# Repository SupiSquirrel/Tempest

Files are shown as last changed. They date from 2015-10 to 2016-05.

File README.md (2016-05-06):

# Tempest
Tempest: Etek 5 / GTek / Drone 2 / Clone 5 / Shocker SFT/NXT Paintball Board

This product is open source!

## Hardware
The hardware is released under [Creative Commons ShareAlike 4.0 International](https://creativecommons.org/licenses/by-sa/4.0/).

Please use, reuse, and modify these files as you see fit. Please release anything derivative under the same license.

Distributed as-is; no warranty is given.

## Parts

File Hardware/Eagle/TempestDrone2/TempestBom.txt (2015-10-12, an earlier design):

Partlist

Exported from TempestDrone2.brd at 09.10.2015 22:12:44

EAGLE Version 6.6.0 Copyright (c) 1988-2014 CadSoft

Assembly variant: 

Part     Value                Package            Library  Position (mm)         Orientation

C1       dnp                  _0603MP            squirrel (22.6678 71.338)      R180
C2       dnp                  _0603MP            squirrel (22.727 76.1532)      R180
C3       2.2µ                 C0805              squirrel (31 58.9)             R0                  0.07
C4       100n                 _0603MP            squirrel (26.594 76.0612)      R180
C5       100n                 _0603MP            squirrel (26.389 67.6968)      R0
C6       100n                 _0603MP            squirrel (29.161 76.4612)      R0
C7       2.2µ                 C0805              squirrel (27.8 62)             R270                0.07
C9       100n                 _0603MP            squirrel (15.515471875 39.60048125) R90
C10      2.2µ                 _0603MP            squirrel (15.515475 36.90048125) R90               0.07
C24      22µ                  C1206              squirrel (30.7608 81.1564)     R90                 0.08
CON1     MOLEX_51281          MOLEX_51281        squirrel (24.49863125 82.601815625) R164           0,54
CON2     B2B-ZR               S2B-ZR             squirrel (30.7 57.3)           R0                  0.08
CON3     FE05-2HD-2           FE02-2-HD-2        squirrel (38.1 69.8)           R75                 0,39
CON5     FE05-2HD-2           FE02-2-HD-2        squirrel (22.915475 50.20048125) R180              0,39
CON7     FE05-2HD-2           FE02-2-HD-2        squirrel (37.707 79.5122)      R345                0,57
D1       SOD123               SOD123             squirrel (27.497 56.9398)      R270                0,15
D3       BAT54C               SOT23              diode    (35.776 60.8942)      R270                0.04
IC1      ATSAMD21E            QFN-32             squirrel (28.234 72.0622)      R270                2.59
LED1     LED-TRICOLORSMD_SIDE RGB-LED-SMD-SIDE   squirrel (45.146184375 31.732578125) R185          0.56
Q1       dnp                  XTAL_32X15         squirrel (23.362 74.5022)      R90
R1       10K                  _0603MP            squirrel (32.3388 76.001)      R90
R2       100K                 _0603MP            squirrel (37.2 58.7)           R90
R3       100K                 _0603MP            squirrel (52.8 62.8)           R0
R4       10K                  _0603MP            squirrel (35.124 57.9728)      R0
R5       18K                  _0603MP            squirrel (25.7612 57.154)      R90
R7       100K                 _0603MP            squirrel (28.015475 49.20048125) R90
R10      390                  _0603MP            squirrel (19.2392 72.1696)     R270
R14      1K                   _0603MP            squirrel (44.7 35.2)           R90
R15      1K                   _0603MP            squirrel (42.5 35.2)           R90
R16      1K                   _0603MP            squirrel (43.6 35.2)           R90
S1       SWITCH-BUTTONSIDE_EZ TACTILE-PTH-SIDEEZ squirrel (44.991284375 20.99961875) R95            0,27
S2       SWITCH-BUTTONSIDE_EZ TACTILE-PTH-SIDEEZ squirrel (46.036003125 10.575375) R95              0,27
S3       SWITCH-BUTTON        D2F-A              squirrel (24.6304 60.17135)    R345                1.36
SW3      PUSHBUTTONMICRO2     PUSHBUTTON-MICRO2  squirrel (36.7122 55.697)      R180                0.72 
U$1      AMS002               AMS00X             AMS00x   (17.215475 46.60048125) R270              8,49
U1       TPS709               SOT23-5            squirrel (31.3 62)             R0                  0.78
---------------------------------------------------------------------------------------------------------
                                                                                                   17.14
                                                                                                   24.32 Fab

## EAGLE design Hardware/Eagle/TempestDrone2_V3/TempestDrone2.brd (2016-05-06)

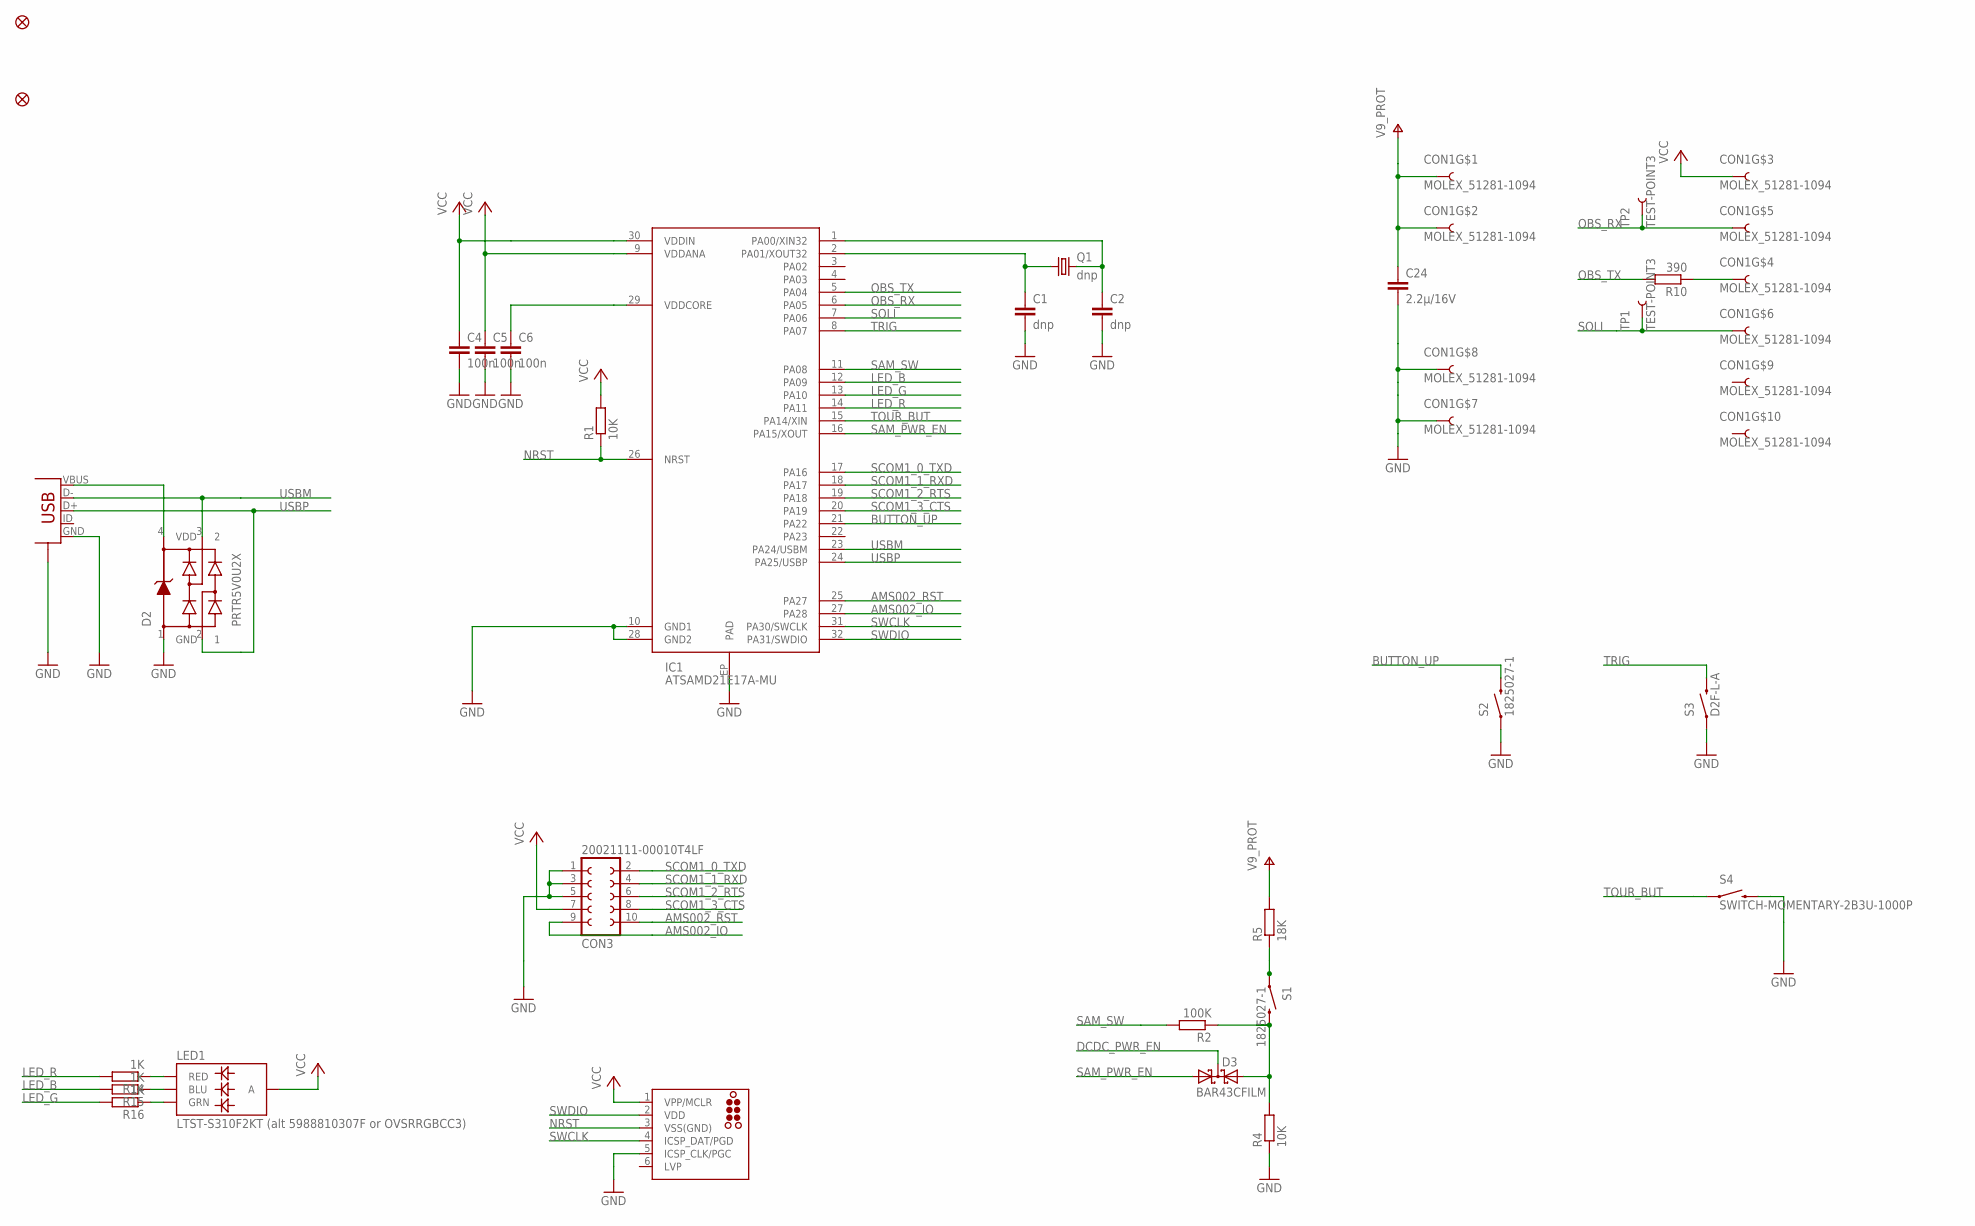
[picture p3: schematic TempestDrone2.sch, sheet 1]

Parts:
C1, C2: dnp; _0603MP
C4, C5, C6: 100n; _0603MP
C24: 2.2µ/16V; C0805
CON1: MOLEX_51281-1094; MOLEX_51281; PART# 51281-1094
CON3: 20021111-00010T4LF; FE02-2-HD-2; PART# 20021111-00010T4LF
CON4: USB-MICRO-A; USB-MICROB; PART# ZX62-B-5PA(11)
D2: PRTR5V0U2X; AUTOPILOT_SOT143B; PART# PRTR5V0U2X
D3: BAR43CFILM; SOT23
FID1, FID6: FIDUCIALUFIDUCIAL; MICRO-FIDUCIAL
IC1: ATSAMD21E17A-MU; QFN-32; PART# ATSAMD21E17A-MU
LED1: LTST-S310F2KT (alt 5988810307F or OVSRRGBCC3); RGB-LED-SMD-SIDE; PART# LTST-S310F2KT
Q1: dnp; XTAL_32X15
R1, R4: 10K; _0603MP
R2: 100K; _0603MP
R5: 18K; _0603MP
R10: 390; _0603MP
R14, R15, R16: 1K; _0603MP
S1, S2: 1825027-1; TACTILE-PTH-SIDEEZ; PART# 1-1825027-1
S3: D2F-L-A; D2F-A; PART# D2F-L-A
S4: SWITCH-MOMENTARY-2B3U-1000P; PUSHBUTTON-MICRO3; PART# B3U-1000P
TC2030-CTX-NL: dnp; TC2030-MCP-NL
TP1, TP2: TEST-POINT3; PAD.03X.03

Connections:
AMS002_IO: CON3.9, IC1.27 (PA28)
AMS002_RST: CON3.10, IC1.25 (PA27)
BUTTON_UP: IC1.21 (PA22), S2.2
DCDC_PWR_EN: D3.3 (CC); also elsewhere on the board
GND: C1.2, C2.2, C4.2, C5.2, C6.2, C24.2, CON1.7, CON1.8, CON3.1, CON3.3, CON3.5, CON4.GND, CON4.GND@1 (GND), CON4.GND@2 (GND), CON4.GND@3 (GND), CON4.GND@4 (GND), CON4.GND@5 (GND), CON4.GND@6 (GND), D2.1 (GND), IC1.10 (GND1), IC1.28 (GND2), IC1.EP (PAD), R4.1, S2.1, S3.COM (1), S4.2A (2), TC2030-CTX-NL.5 (ICSP_CLK/PGC); also elsewhere on the board
LED_B: IC1.12 (PA09), R15.2
LED_G: IC1.13 (PA10), R16.2
LED_R: IC1.14 (PA11), R14.2
unnamed: C2.1, IC1.1 (PA00/XIN32), Q1.2
unnamed: C6.1, IC1.29 (VDDCORE)
unnamed: C1.1, IC1.2 (PA01/XOUT32), Q1.1
unnamed: CON4.VBUS, D2.4 (VDD)
unnamed: D3.2 (A2), R2.1, R4.2, S1.2
unnamed: CON1.4, R10.1
unnamed: R5.1, S1.1
unnamed: LED1.1 (RED), R14.1
unnamed: LED1.3 (BLU), R15.1
unnamed: LED1.2 (GRN), R16.1
NRST: IC1.26 (NRST), R1.1, TC2030-CTX-NL.3 (VSS(GND))
OBS_RX: CON1.5, IC1.6 (PA05), TP2.P$1
OBS_TX: IC1.5 (PA04), R10.2
SAM_PWR_EN: D3.1 (A1), IC1.16 (PA15/XOUT)
SAM_SW: IC1.11 (PA08), R2.2
SCOM1_0_TXD: CON3.2, IC1.17 (PA16)
SCOM1_1_RXD: CON3.4, IC1.18 (PA17)
SCOM1_2_RTS: CON3.6, IC1.19 (PA18)
SCOM1_3_CTS: CON3.8, IC1.20 (PA19)
SOLI: CON1.6, IC1.7 (PA06), TP1.P$1
SWCLK: IC1.31 (PA30/SWCLK), TC2030-CTX-NL.4 (ICSP_DAT/PGD)
SWDIO: IC1.32 (PA31/SWDIO), TC2030-CTX-NL.2 (VDD)
TOUR_BUT: IC1.15 (PA14/XIN), S4.1A (1)
TRIG: IC1.8 (PA07), S3.NO (2)
USBM: CON4.D-, D2.3 (2), IC1.23 (PA24/USBM)
USBP: CON4.D+, D2.2 (1), IC1.24 (PA25/USBP)
V9_PROT: C24.1, CON1.1, CON1.2, R5.2; also elsewhere on the board
VCC: C4.1, C5.1, CON1.3, CON3.7, IC1.9 (VDDANA), IC1.30 (VDDIN), LED1.4 (A), R1.2, TC2030-CTX-NL.1 (VPP/MCLR); also elsewhere on the board

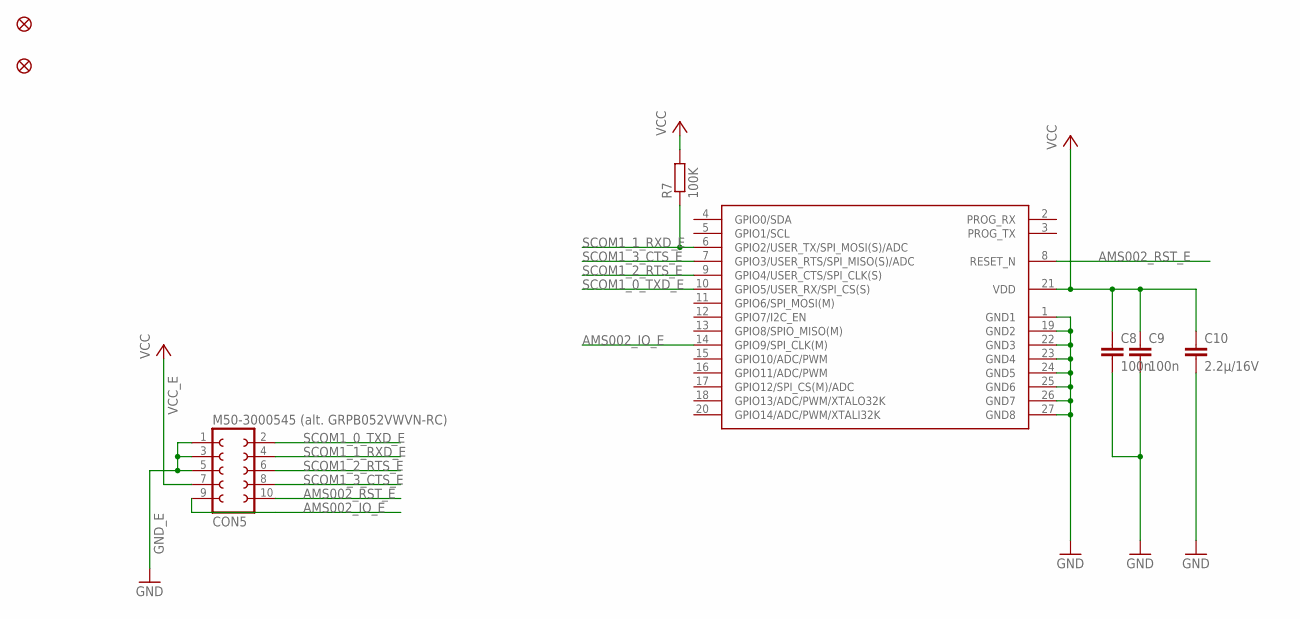
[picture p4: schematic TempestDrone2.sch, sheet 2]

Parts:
C8, C9: 100n; _0603MP
C10: 2.2µ/16V; C0805
CON5: M50-3000545 (alt. GRPB052VWVN-RC); FE02-2-HD-2; PART# M50-3000545
FID3, FID5: FIDUCIALUFIDUCIAL; MICRO-FIDUCIAL
R7: 100K; _0603MP
U$1: AMS001/AMS002; AMS00X; PART# AMS001 or AMS002

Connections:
AMS002_IO_E: CON5.9, U$1.14 (GPIO9/SPI_CLK(M))
AMS002_RST_E: CON5.10, U$1.8 (RESET_N)
GND_E: C8.2, C9.2, C10.2, CON5.1, CON5.3, CON5.5, U$1.1 (GND1), U$1.19 (GND2), U$1.22 (GND3), U$1.23 (GND4), U$1.24 (GND5), U$1.25 (GND6), U$1.26 (GND7), U$1.27 (GND8)
SCOM1_0_TXD_E: CON5.2, U$1.10 (GPIO5/USER_RX/SPI_CS(S))
SCOM1_1_RXD_E: CON5.4, R7.1, U$1.6 (GPIO2/USER_TX/SPI_MOSI(S)/ADC)
SCOM1_2_RTS_E: CON5.6, U$1.9 (GPIO4/USER_CTS/SPI_CLK(S))
SCOM1_3_CTS_E: CON5.8, U$1.7 (GPIO3/USER_RTS/SPI_MISO(S)/ADC)
VCC_E: C8.1, C9.1, C10.1, CON5.7, R7.2, U$1.21 (VDD)

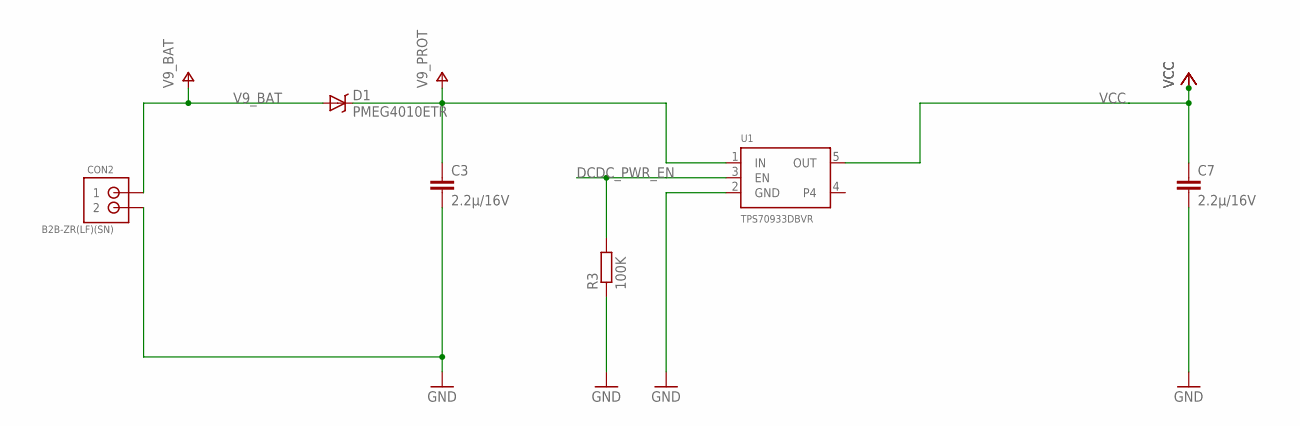
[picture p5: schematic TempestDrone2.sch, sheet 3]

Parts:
C3, C7: 2.2µ/16V; C0805
CON2: B2B-ZR(LF)(SN); S2B-ZR; PART# B2B-ZR(LF)(SN)
D1: PMEG4010ETR; SOD123
R3: 100K; _0603MP
U1: TPS70933DBVR; SOT23-5; PART# TPS70933DBVR

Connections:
DCDC_PWR_EN: R3.2, U1.3 (EN); also elsewhere on the board
GND: C3.2, C7.2, CON2.2, R3.1, U1.2 (GND); also elsewhere on the board
V9_BAT: CON2.1, D1.A
V9_PROT: C3.1, D1.C, U1.1 (IN); also elsewhere on the board
VCC: C7.1, U1.5 (OUT); also elsewhere on the board

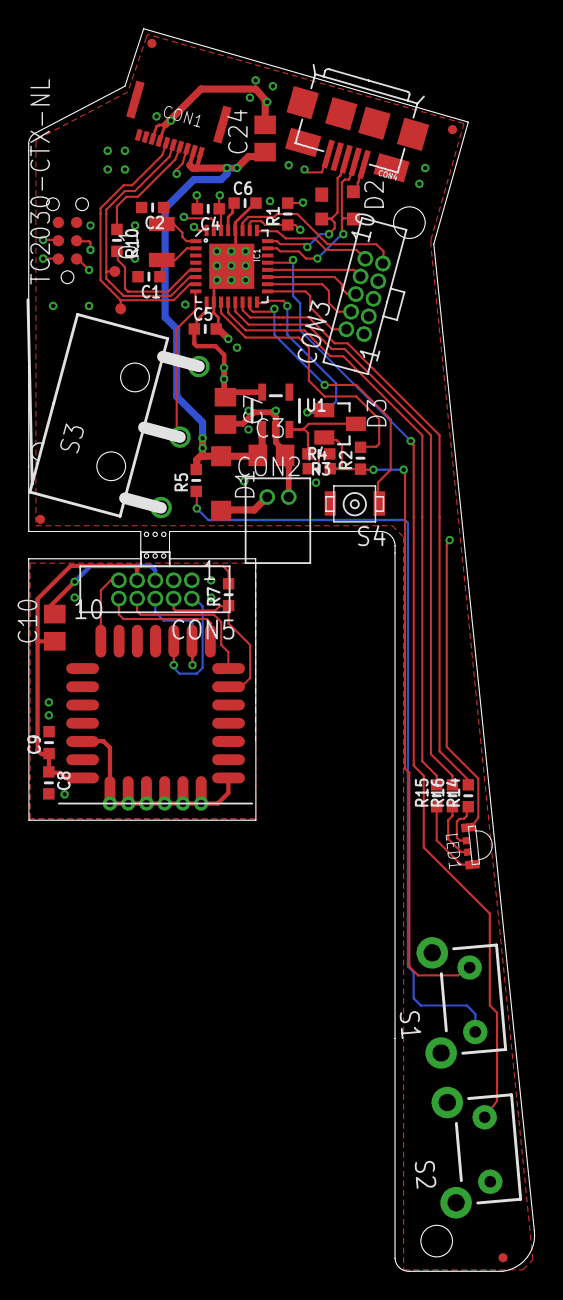
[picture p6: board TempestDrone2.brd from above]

Board: 4 copper layers, 35.2 x 86.5 mm, 45 parts (0 on the bottom side), 45 nets.

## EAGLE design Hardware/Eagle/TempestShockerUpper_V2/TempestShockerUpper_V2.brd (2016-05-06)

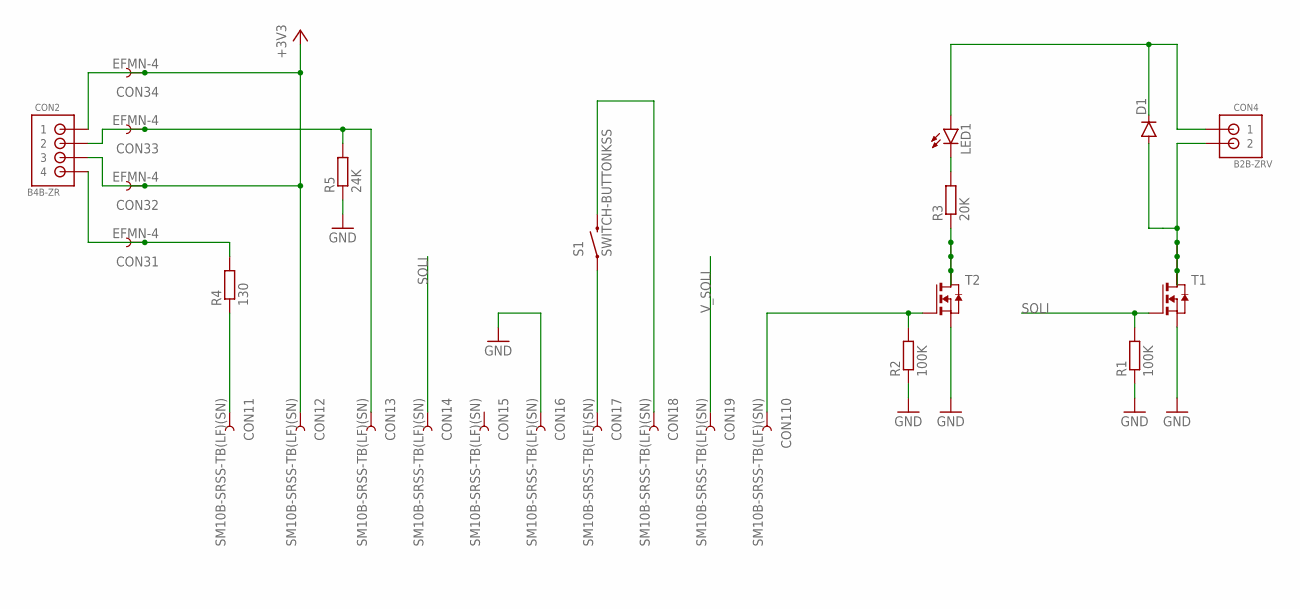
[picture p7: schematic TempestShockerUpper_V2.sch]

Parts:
CON1: SM10B-SRSS-TB(LF)(SN); SM10B-SRSS-TB
CON2: B4B-ZR; S4B-ZR
CON3: EFMN-4
CON4: B2B-ZRV; S2B-ZR-VERT
D1: DIODE-SSOD123; SOD-123
LED1: LED0603; LED-0603
R1, R2: 100K; _0603MP
R3: 20K; _0603MP
R4: 130; _0603MP
R5: 24K; _0603MP
S1: SWITCH-BUTTONKSS; KSS
T1, T2: NMOSSOT23-6; SOT23-6

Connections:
+3V3: CON1.2, CON2.1, CON2.3, CON3.2, CON3.4
GND: CON1.6, R1.1, R2.1, R5.1, T1.4 (S), T2.4 (S)
unnamed: CON2.4, CON3.1, R4.2
unnamed: CON1.1, R4.1
unnamed: CON1.3, CON2.2, CON3.3, R5.2
unnamed: CON1.10, R2.2, T2.3 (G)
unnamed: CON1.7, S1.1
unnamed: CON1.8, S1.2
unnamed: LED1.C, R3.2
unnamed: R3.1, T2.1 (D), T2.2 (D1), T2.5 (D2), T2.6 (D3)
unnamed: CON4.2, D1.A, T1.1 (D), T1.2 (D1), T1.5 (D2), T1.6 (D3)
SOLI: CON1.4, R1.2, T1.3 (G)
V_SOLI: CON1.9, CON4.1, D1.C, LED1.A

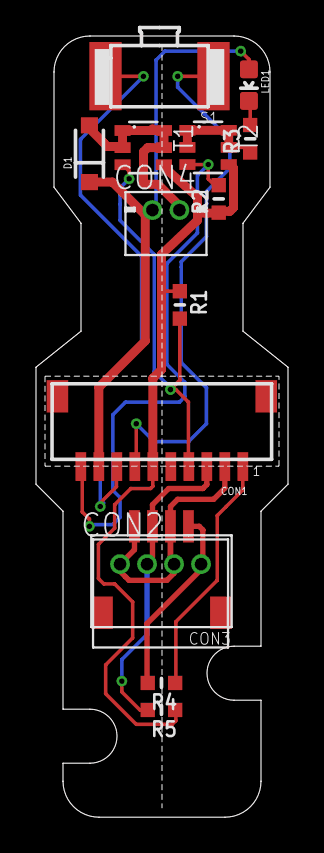
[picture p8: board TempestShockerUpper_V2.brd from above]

Board: 2 copper layers, 14.0 x 43.4 mm, 15 parts (0 on the bottom side), 13 nets.

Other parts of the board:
U$2: SHOCKER-OUTLINE-UPPER-SHORT

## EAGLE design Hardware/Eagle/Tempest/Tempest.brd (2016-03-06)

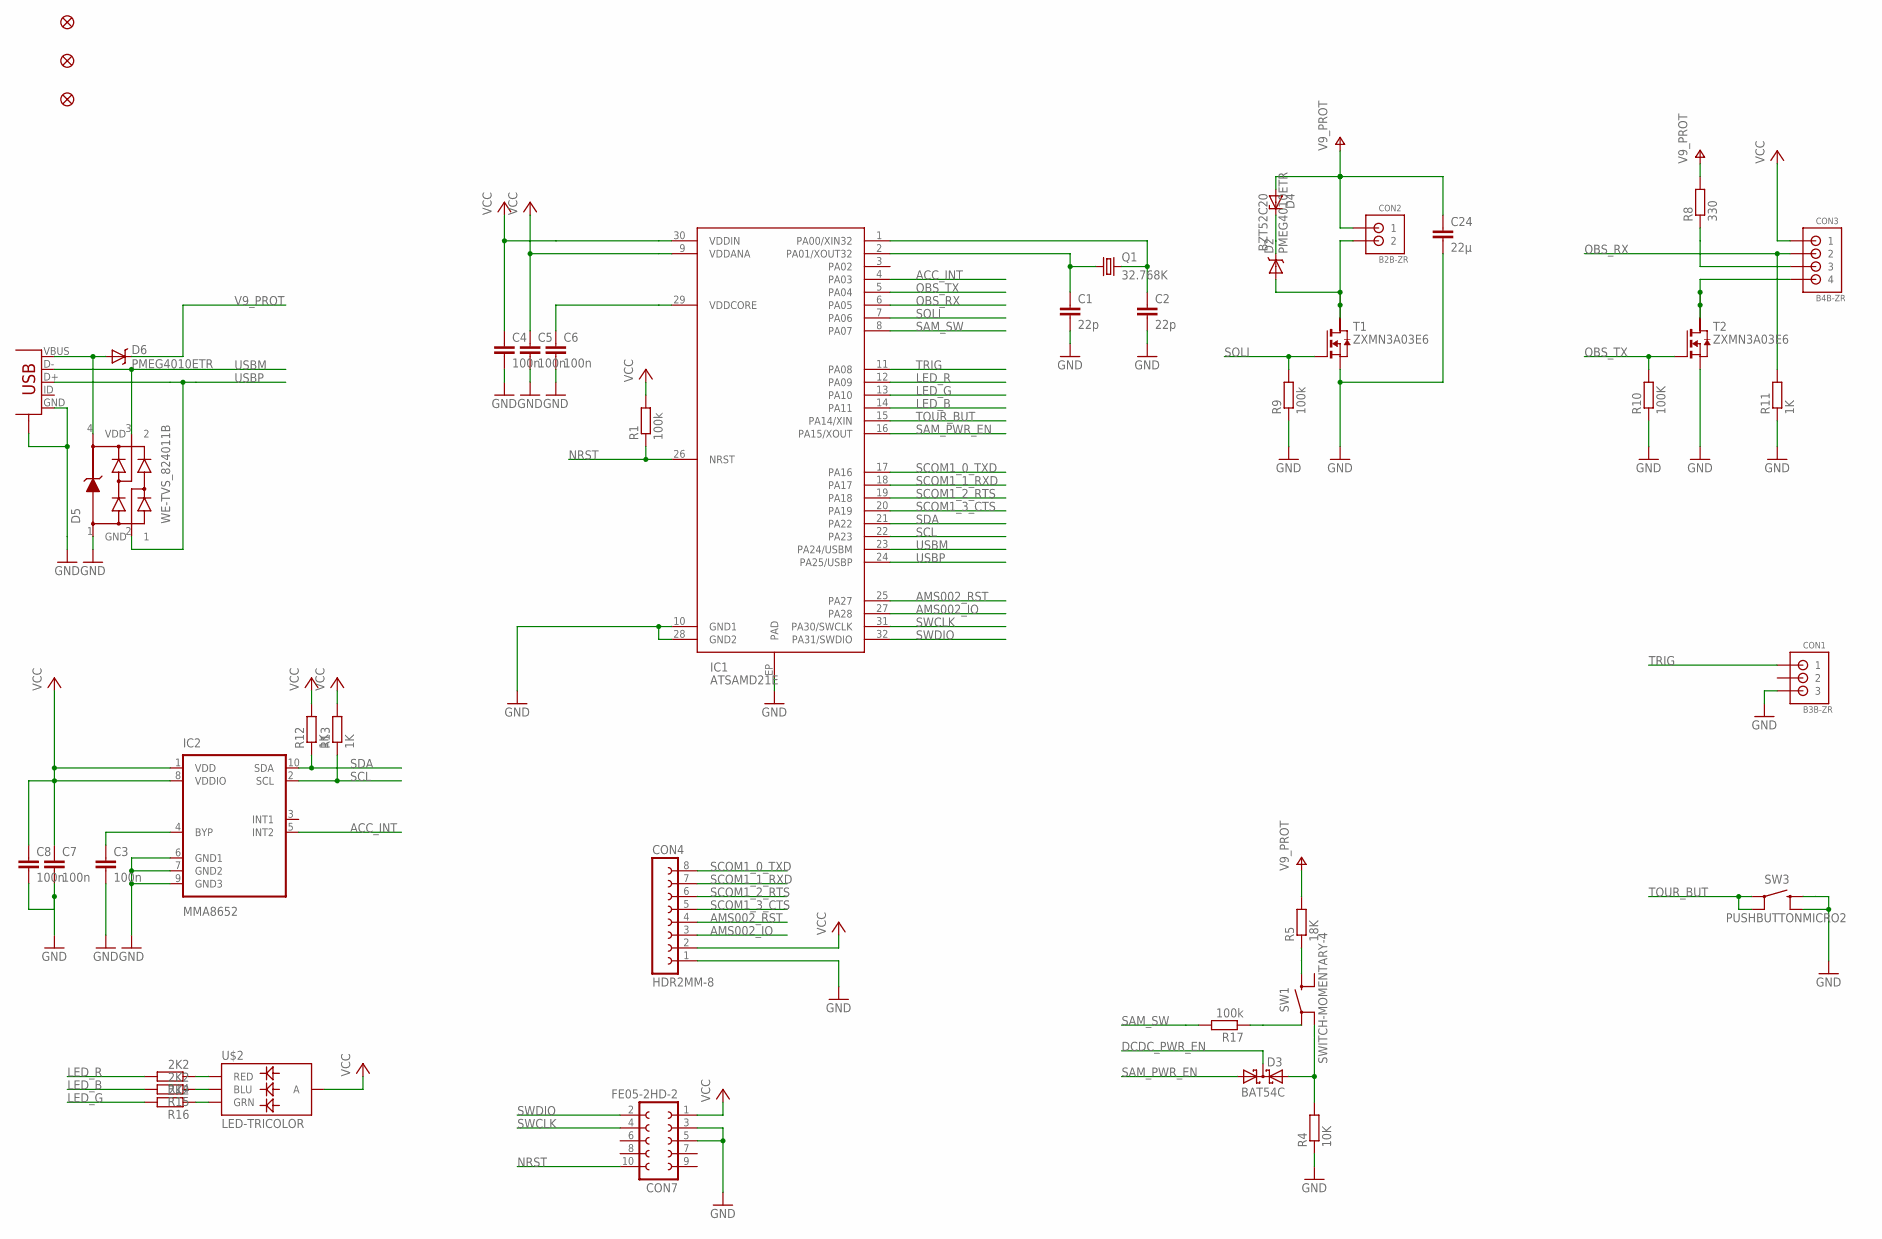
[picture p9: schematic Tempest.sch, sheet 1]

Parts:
C1, C2: 22p; _0603MP
C3, C4, C5, C6, C7, C8: 100n; _0603MP
C24: 22µ; C1206
CON1: B3B-ZR; S3B-ZR
CON2: B2B-ZR; S2B-ZR
CON3: B4B-ZR; S4B-ZR
CON4: HDR2MM-8
CON6: USB-MICRO-A; USB-MICROB
CON7: FE05-2HD-2; FE02-2-HD-2
D2, D6: PMEG4010ETR; SOD123
D3: BAT54C; SOT23
D4: BZT52C20; SOD123
D5: WE-TVS_824011B; AUTOPILOT_SOT143B
FID1, FID2, FID6: FIDUCIALUFIDUCIAL; MICRO-FIDUCIAL
IC1: ATSAMD21E; QFN-32
IC2: MMA8652; DFN-10
Q1: 32.768K; XTAL_32X15
R1, R9, R17: 100k; _0603MP
R4: 10K; _0603MP
R5: 18K; _0603MP
R8: 330; R0805
R10: 100K; _0603MP
R11, R12, R13: 1K; _0603MP
R14, R15, R16: 2K2; _0603MP
SW1: SWITCH-MOMENTARY-4; TACTILE_SWITCH_TALL
SW3: PUSHBUTTONMICRO2; PUSHBUTTON-MICRO2
T1, T2: ZXMN3A03E6; SOT23-6
U$2: LED-TRICOLOR; LED-TRICOLOR-SMD

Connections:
ACC_INT: IC1.4 (PA03), IC2.5 (INT2)
AMS002_IO: CON4.3, IC1.27 (PA28)
AMS002_RST: CON4.4, IC1.25 (PA27)
DCDC_PWR_EN: D3.3 (CC); also elsewhere on the board
GND: C1.2, C2.2, C3.2, C4.2, C5.2, C6.2, C7.2, C8.2, C24.2, CON1.3, CON4.1, CON6.GND, CON6.GND@1 (GND), CON6.GND@2 (GND), CON6.GND@3 (GND), CON6.GND@4 (GND), CON6.GND@5 (GND), CON6.GND@6 (GND), CON7.3, CON7.5, D5.1 (GND), IC1.10 (GND1), IC1.28 (GND2), IC1.EP (PAD), IC2.6 (GND1), IC2.7 (GND2), IC2.9 (GND3), R4.1, R9.1, R10.1, R11.1, SW3.2A (2), SW3.2B (2A), T1.4 (S), T2.4 (S); also elsewhere on the board
LED_B: IC1.14 (PA11), R15.2
LED_G: IC1.13 (PA10), R16.2
LED_R: IC1.12 (PA09), R14.2
unnamed: C2.1, IC1.1 (PA00/XIN32), Q1.2
unnamed: C6.1, IC1.29 (VDDCORE)
unnamed: C1.1, IC1.2 (PA01/XOUT32), Q1.1
unnamed: D3.2 (A2), R4.2, SW1.A2 (1A)
unnamed: CON2.2, D2.A, T1.1 (D), T1.2 (D1), T1.6 (D3)
unnamed: R5.1, SW1.B1 (2)
unnamed: R17.1, SW1.A1 (1)
unnamed: C3.1, IC2.4 (BYP)
unnamed: CON3.4, T2.1 (D), T2.2 (D1), T2.6 (D3)
unnamed: CON3.3, R8.1
unnamed: D2.C, D4.C
unnamed: CON6.VBUS, D5.4 (VDD), D6.A
unnamed: R14.1, U$2.2 (RED)
unnamed: R15.1, U$2.3 (BLU)
unnamed: R16.1, U$2.4 (GRN)
NRST: CON7.10, IC1.26 (NRST), R1.1
OBS_RX: CON3.2, IC1.6 (PA05), R11.2
OBS_TX: IC1.5 (PA04), R10.2, T2.3 (G)
SAM_PWR_EN: D3.1 (A1), IC1.16 (PA15/XOUT)
SAM_SW: IC1.8 (PA07), R17.2
SCL: IC1.22 (PA23), IC2.2 (SCL), R13.1
SCOM1_0_TXD: CON4.8, IC1.17 (PA16)
SCOM1_1_RXD: CON4.7, IC1.18 (PA17)
SCOM1_2_RTS: CON4.6, IC1.19 (PA18)
SCOM1_3_CTS: CON4.5, IC1.20 (PA19)
SDA: IC1.21 (PA22), IC2.10 (SDA), R12.1
SOLI: IC1.7 (PA06), R9.2, T1.3 (G)
SWCLK: CON7.4, IC1.31 (PA30/SWCLK)
SWDIO: CON7.2, IC1.32 (PA31/SWDIO)
TOUR_BUT: IC1.15 (PA14/XIN), SW3.1A (1), SW3.1B (1A)
TRIG: CON1.1, IC1.11 (PA08)
USBM: CON6.D-, D5.3 (2), IC1.23 (PA24/USBM)
USBP: CON6.D+, D5.2 (1), IC1.24 (PA25/USBP)
V9_PROT: C24.1, CON2.1, D4.A, D6.C, R5.2, R8.2; also elsewhere on the board
VCC: C4.1, C5.1, C7.1, C8.1, CON3.1, CON4.2, CON7.1, IC1.9 (VDDANA), IC1.30 (VDDIN), IC2.1 (VDD), IC2.8 (VDDIO), R1.2, R12.2, R13.2, U$2.1 (A); also elsewhere on the board

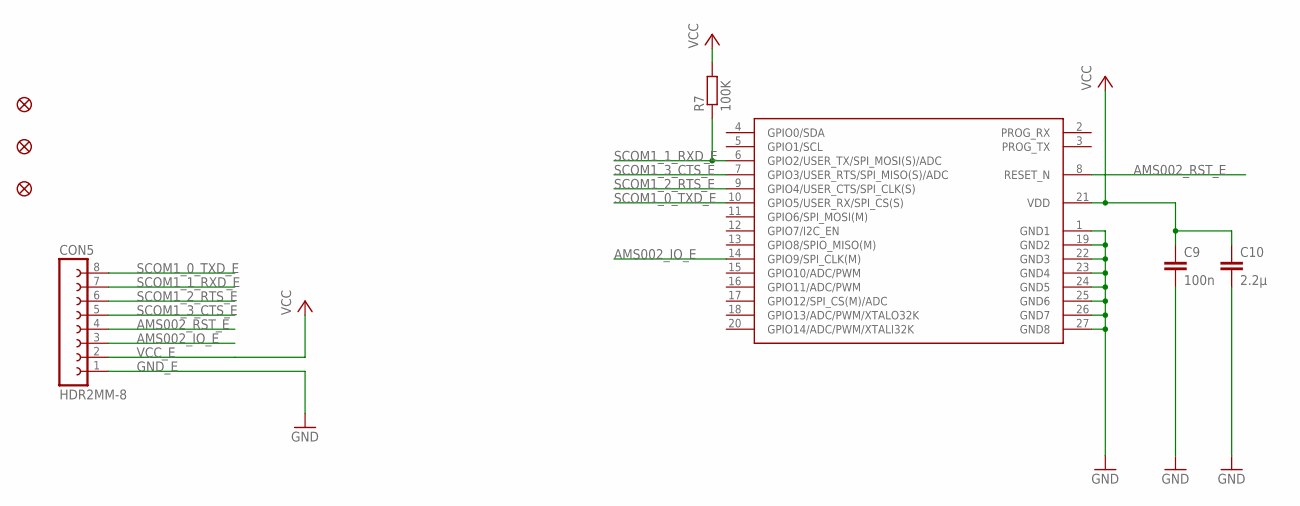
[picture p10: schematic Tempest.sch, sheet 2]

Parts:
C9: 100n; _0603MP
C10: 2.2µ; _0603MP
CON5: HDR2MM-8
FID3, FID4, FID5: FIDUCIALUFIDUCIAL; MICRO-FIDUCIAL
R7: 100K; _0603MP
U$1: AMS002; AMS00X

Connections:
AMS002_IO_E: CON5.3, U$1.14 (GPIO9/SPI_CLK(M))
AMS002_RST_E: CON5.4, U$1.8 (RESET_N)
GND_E: C9.2, C10.2, CON5.1, U$1.1 (GND1), U$1.19 (GND2), U$1.22 (GND3), U$1.23 (GND4), U$1.24 (GND5), U$1.25 (GND6), U$1.26 (GND7), U$1.27 (GND8)
SCOM1_0_TXD_E: CON5.8, U$1.10 (GPIO5/USER_RX/SPI_CS(S))
SCOM1_1_RXD_E: CON5.7, R7.1, U$1.6 (GPIO2/USER_TX/SPI_MOSI(S)/ADC)
SCOM1_2_RTS_E: CON5.6, U$1.9 (GPIO4/USER_CTS/SPI_CLK(S))
SCOM1_3_CTS_E: CON5.5, U$1.7 (GPIO3/USER_RTS/SPI_MISO(S)/ADC)
VCC_E: C9.1, C10.1, CON5.2, R7.2, U$1.21 (VDD)

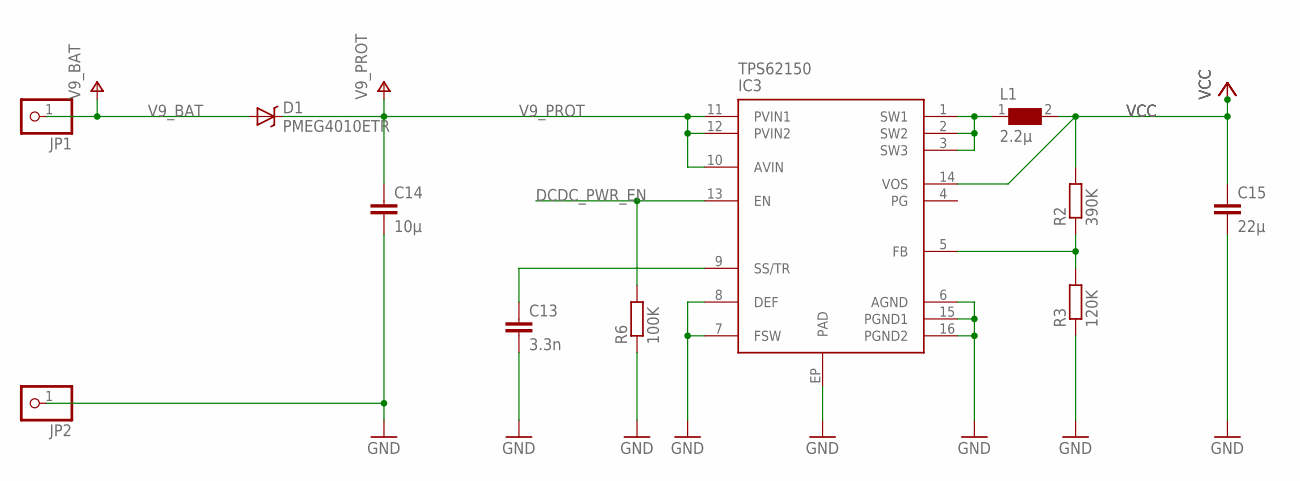
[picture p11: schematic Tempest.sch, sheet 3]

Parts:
C13: 3.3n; _0603MP
C14: 10µ; C1206
C15: 22µ; C1206
D1: PMEG4010ETR; SOD123
IC3: TPS62150; QFN-16
JP1, JP2: PINHD-1X1; 1X01
L1: 2.2µ; WE-TPC_2828
R2: 390K; _0603MP
R3: 120K; _0603MP
R6: 100K; _0603MP

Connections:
DCDC_PWR_EN: IC3.13 (EN), R6.2; also elsewhere on the board
GND: C13.2, C14.2, C15.2, IC3.6 (AGND), IC3.7 (FSW), IC3.8 (DEF), IC3.15 (PGND1), IC3.16 (PGND2), IC3.EP (PAD), JP2.1, R3.1, R6.1; also elsewhere on the board
unnamed: C13.1, IC3.9 (SS/TR)
unnamed: IC3.1 (SW1), IC3.2 (SW2), IC3.3 (SW3), L1.1
unnamed: IC3.5 (FB), R2.1, R3.2
V9_BAT: D1.A, JP1.1
V9_PROT: C14.1, D1.C, IC3.10 (AVIN), IC3.11 (PVIN1), IC3.12 (PVIN2); also elsewhere on the board
VCC: C15.1, IC3.14 (VOS), L1.2, R2.2; also elsewhere on the board

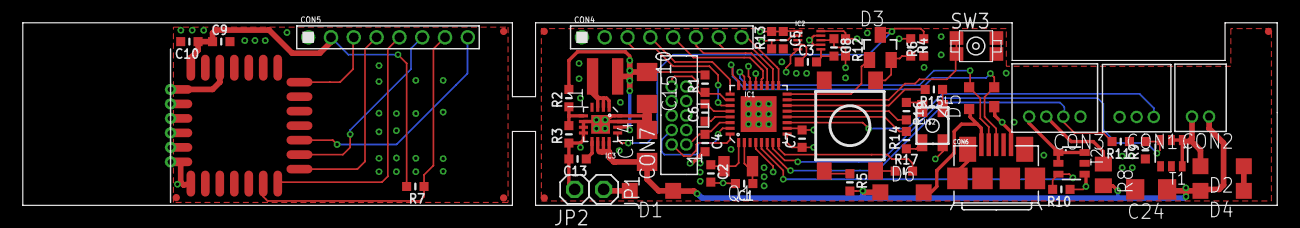
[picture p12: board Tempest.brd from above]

Board: 4 copper layers, 110.0 x 16.0 mm, 63 parts (0 on the bottom side), 55 nets.

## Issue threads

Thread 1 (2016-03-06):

BOM for original Tempest board

DirtyEngineer, 2016-03-06:
I'd like to try assembling one of your original Tempest boards. Is there a BOM for it? I'm specifically trying to source the mosfet's (T1/T2), the zener diode (D4) and the schottky diode (D2).

Also can you clarify the purpose of the 22uf capacitor paralleled with the mosfet?

Any help would be much appreciated.

SupiSquirrel, 2016-03-06:
Hi,

I updated the eagle files for Tempest for you. I added part #s for the fets and diodes.

Please note that
- I also added a 100K resistor between the power switch and the controller "sense" pin. Without this resistor, when pushing the button, current flows over the clamp diodes trying to power the 3.3V rail, which results in a voltage that is too low to enable the voltage reg.
- I never tried the accelerometer and USB.

The 22uf cap (parallel to the mosfet in series with the solenoid, close to the solenoid connector) is intended to buffer the current drawn from the solenoid. I saw this on some commercial boards.

DirtyEngineer, 2016-03-09:
Thanks for the update!  I really enjoy seeing your designs. Keep up the great work.

Closed 2016-03-09.

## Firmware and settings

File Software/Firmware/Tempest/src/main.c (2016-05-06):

/*

	Copyright (C) 2015 Matthias Friedrich

	This file is part of Tempest Firmware.

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
 */ 

/*
 * Include header files for all drivers that have been imported from
 * Atmel Software Framework (ASF).
 */


#include <asf.h>
#include "IO_Discretes.h"
#include "IO_SysTickTimer.h"
#include "IO_ExtInt.h"
#include "IO_Pwm.h"
#include "IO_Analogs.h"
#include "IO_SerialUart.h"
#include "CFG_Config.h"
#include "TRG_Trigger.h"
#include "FM_DetermineRof.h"
#include "ACT_Led.h"
#include "ACT_Eye.h"
#include "ACT_Solenoid.h"
#include "ACT_BatteryMonitor.h"
#include "FM_FireMode.h"
#include "COM_CommandInterpreter.h"
#include "COM_Ams001.h"
#include "GBL_Defines.h"
#include "GBL_LedModing.h"
#include "IO_Eeprom.h"


int main(void)
{

	bool WaitForPowerOn;
	
	uint32_t UpSwitchPushedCounter    = 0;
	uint32_t UpSwitchPushedStartTick  = 0;
	
	system_init();
	system_clock_source_disable(SYSTEM_CLOCK_SOURCE_XOSC32K);
	
	IO_Discretes_Initialize();
	IO_SysTickTimer_Initialize();
	IO_SerialUart_Initialize();
	IO_ExtInt_Initialize();
	IO_Pwm_Initialize();
	IO_Analogs_Initialize();
	IO_Eeprom_Initialize();
	
	
	CFG_Config_Initialize();
	
	ACT_Solenoid_Initialize();
	
	ACT_BatteryMonitor_Initialize();

	TRG_Trigger_Initialize();
	
	ACT_Eye_Initialize();
	
	FM_FireMode_Initialize();

	ACT_Led_Initialize();
	
	COM_CommandInterpreter_Initialize();
	
	GBL_LedModing_Initialize();
	
	COM_Ams001_Initialize();
	


	WaitForPowerOn = true;
	
	
	
	do {
		IO_Analogs_Update();
		ACT_Led_Update();
		ACT_BatteryMonitor_Update();
		
		if (ACT_BatteryMonitor_GetButtonPushed()) {
			ACT_Led_SetStepBrightnessR(&ACT_Led_Pattern_FastFlash);
			ACT_Led_SetStepBrightnessG(&ACT_Led_Pattern_FastFlash);
		}
		
		if (ACT_BatteryMonitor_GetButtonPushedLongerThan(IO_SYSTICKTIMER_TICKS_PER_SEC / 2)) {
			WaitForPowerOn = false;
		}
		
	} while (WaitForPowerOn);
	
	// enable dcdc power regulator
	IO_Discretes_SetOutputActive(IO_DISCRETES_CHANNEL_POWER_ENABLE);
	IO_Discretes_SetOutputActive(IO_DISCRETES_CHANNEL_LED_POWER);

	
	ACT_BatteryMonitor_ResetButtonPushedTimer();
	
	
	uint32_t nextSecTicks = IO_SysTickTimer_GetTicks() + IO_SYSTICKTIMER_TICKS_PER_SEC;

	while (true) {
		// debug: measure runtime of main loop
		// port_pin_set_output_level(PIN_PA18, true);
		
		IO_Analogs_Update();
		
		ACT_BatteryMonitor_Update();
		
		ACT_Eye_Update();
		
		TRG_Trigger_Update();
		
		ACT_Solenoid_Update();
		
		FM_FireMode_Update();
		
		ACT_Led_Update();
		
		FM_DetermineRof_Update();
		
		COM_CommandInterpreter_Update();
		
		GBL_LedModing_Update();
		
		COM_Ams001_Update();
		
		IO_SerialUart_Update(); 
		
		// debug printout
		if ((IO_SysTickTimer_GetTicks() >= nextSecTicks) && (false)) {
			nextSecTicks = IO_SysTickTimer_GetTicks() + IO_SYSTICKTIMER_TICKS_PER_SEC / 10;
			// printf("");
		}
		
		if (IO_Discretes_GetInputIsSet(IO_DISCRETES_CHANNEL_UP_SWITCH)) {
			UpSwitchPushedCounter ++;
		} else {
			UpSwitchPushedCounter   = 0;
			UpSwitchPushedStartTick = IO_SysTickTimer_GetTicks();
		}
		
		if (IO_SysTickTimer_GetTicks() > (UpSwitchPushedStartTick + IO_SYSTICKTIMER_TICKS_PER_SEC * 1)) {
			// toggle eyes
			if (CFG_Config_GetUserSettingEyesOn() == ACT_SOENOID_EYE_MODE_ACTIVE) {
				CFG_Config_SetUserParameter(CFG_CONFIG_USER_MODIFIABLE_PARAMETER_EYES_ON, ACT_SOENOID_EYE_MODE_INACTIVE);
			} else {
				CFG_Config_SetUserParameter(CFG_CONFIG_USER_MODIFIABLE_PARAMETER_EYES_ON, ACT_SOENOID_EYE_MODE_ACTIVE);
			}
			
			UpSwitchPushedStartTick = IO_SysTickTimer_GetTicks();
		}
		
		// if button is pressed > 5s, power down system.
		if (ACT_BatteryMonitor_GetButtonPushedLongerThan(IO_SYSTICKTIMER_TICKS_PER_SEC * 3)) {
			
			CFG_Config_Save();
			
			ACT_Led_SetStepBrightnessB(&ACT_Led_Pattern_Off);
			ACT_Led_SetStepBrightnessR(&ACT_Led_Pattern_FastFlash);
			ACT_Led_SetStepBrightnessG(&ACT_Led_Pattern_Off);
			
			IO_Discretes_SetOutputInactive(IO_DISCRETES_CHANNEL_POWER_ENABLE);
			
			do {
				ACT_Led_Update();
			} while (true);
		}
		
		// debug: measure runtime of main loop
		//port_pin_set_output_level(PIN_PA18, false);
	}
}

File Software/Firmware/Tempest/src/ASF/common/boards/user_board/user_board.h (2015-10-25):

/**
 * \file
 *
 * \brief User board definition template
 *
 */

 /* This file is intended to contain definitions and configuration details for
 * features and devices that are available on the board, e.g., frequency and
 * startup time for an external crystal, external memory devices, LED and USART
 * pins.
 */

#ifndef USER_BOARD_H
#define USER_BOARD_H

#include <conf_board.h>

// External oscillator settings.
// Uncomment and set correct values if external oscillator is used.

// External oscillator frequency
#define BOARD_XOSC_HZ          18432000

// External oscillator type.
//!< External clock signal
//#define BOARD_XOSC_TYPE        XOSC_TYPE_EXTERNAL
//!< 32.768 kHz resonator on TOSC
//#define BOARD_XOSC_TYPE        XOSC_TYPE_32KHZ
//!< 0.4 to 16 MHz resonator on XTALS
//#define BOARD_XOSC_TYPE        XOSC_TYPE_XTAL

/** Board oscillator settings */
#define BOARD_FREQ_SLCK_XTAL		(32768U)
#define BOARD_FREQ_SLCK_BYPASS		(32768U)
#define BOARD_FREQ_MAINCK_XTAL		(18432000U)
#define BOARD_FREQ_MAINCK_BYPASS	(18432000U)

/** Master clock frequency */
#define BOARD_MCK					CHIP_FREQ_CPU_MAX

// External oscillator startup time
#define BOARD_OSC_STARTUP_US  15625



/*! LED #0 "L" pin definition (red) */
#define LED_0_NAME      "redLed"
#define LED0_GPIO       (PIO_PB0_IDX)
#define LED0_FLAGS      (PIO_TYPE_PIO_OUTPUT_1 | PIO_DEFAULT)
#define LED0_ACTIVE_LEVEL 0

#define PIN_LED_0       {1 << 0, PIOB, ID_PIOB, PIO_OUTPUT_0, PIO_DEFAULT}
#define PIN_LED_0_MASK  (1 << 0)
#define PIN_LED_0_PIO   PIOB
#define PIN_LED_0_ID    ID_PIOB
#define PIN_LED_0_TYPE  PIO_OUTPUT_0
#define PIN_LED_0_ATTR  PIO_DEFAULT

/*! LED #1 pin definition (green) */
#define LED_1_NAME      "greenLed"
#define LED1_GPIO       (PIO_PB1_IDX)
#define LED1_FLAGS      (PIO_TYPE_PIO_OUTPUT_1 | PIO_DEFAULT)
#define LED1_ACTIVE_LEVEL 0

#define PIN_LED_1       {1 << 1, PIOB, ID_PIOB, PIO_OUTPUT_1, PIO_DEFAULT}
#define PIN_LED_1_MASK  (1 << 1)
#define PIN_LED_1_PIO   PIOB
#define PIN_LED_1_ID    ID_PIOB
#define PIN_LED_1_TYPE  PIO_OUTPUT_1
#define PIN_LED_1_ATTR  PIO_DEFAULT

#define RF231_RST_GPIO       (PIO_PA31_IDX)
#define RF231_RST_FLAGS      (PIO_TYPE_PIO_OUTPUT_1 | PIO_DEFAULT)

#define RF231_SLP_GPIO       (PIO_PA0_IDX)
#define RF231_SLP_FLAGS      (PIO_TYPE_PIO_OUTPUT_1 | PIO_DEFAULT)

//#define RF231_IRQ_GPIO       (PIO_PA1_IDX)
//#define RF231_IRQ_FLAGS      (PIO_TYPE_PIO_INPUT | PIO_DEFAULT)
#define RF231IRQ_NAME    "RF231IRQ"
#define GPIO_RF231IRQ    (PIO_PA1_IDX)
#define GPIO_RF231IRQ_FLAGS    (PIO_INPUT | /*PIO_PULLUP | PIO_DEBOUNCE |*/ PIO_IT_RISE_EDGE)

#define PIN_RF231IRQ    {PIO_PA1, PIOA, ID_PIOA, PIO_INPUT, /*PIO_PULLUP | PIO_DEBOUNCE |*/ PIO_IT_RISE_EDGE}
#define PIN_RF231IRQ_MASK PIO_PA1
#define PIN_RF231IRQ_PIO PIOA
#define PIN_RF231IRQ_ID ID_PIOA
#define PIN_RF231IRQ_TYPE PIO_INPUT
#define PIN_RF231IRQ_ATTR /* PIO_PULLUP | PIO_DEBOUNCE |*/ PIO_IT_RISE_EDGE


//#define PUSHB_GPIO           (PIO_PB13_IDX)
//#define PUSHB_FLAGS          (PIO_TYPE_PIO_INPUT | PIO_DEFAULT)
/** pushbutton definition. pull-up + debounce + interrupt on rising edge. */
#define PUSHBUTTON_NAME    "PB1"
#define GPIO_PUSHBUTTON    (PIO_PB13_IDX)
#define GPIO_PUSHBUTTON_FLAGS    (PIO_INPUT | PIO_PULLUP | PIO_DEBOUNCE | PIO_IT_RISE_EDGE)

#define PIN_PUSHBUTTON    {PIO_PB13, PIOB, ID_PIOB, PIO_INPUT, PIO_PULLUP | PIO_DEBOUNCE | PIO_IT_RISE_EDGE}
#define PIN_PUSHBUTTON_MASK PIO_PB13
#define PIN_PUSHBUTTON_PIO PIOB
#define PIN_PUSHBUTTON_ID ID_PIOB
#define PIN_PUSHBUTTON_TYPE PIO_INPUT
#define PIN_PUSHBUTTON_ATTR PIO_PULLUP | PIO_DEBOUNCE | PIO_IT_RISE_EDGE

/*
#define GPIO_PA22    		 (PIO_PA22_IDX)
#define GPIO_PA22_FLAGS      (PIO_INPUT | PIO_DEBOUNCE | PIO_IT_RISE_EDGE)

#define PIN_PA22    {PIO_PA22, PIOA, ID_PIOA, PIO_INPUT, PIO_DEBOUNCE | PIO_IT_RISE_EDGE}
#define PIN_PA22_MASK PIO_PA22
#define PIN_PA22_PIO PIOA
#define PIN_PA22_ID ID_PIOA
#define PIN_PA22_TYPE PIO_INPUT
#define PIN_PA22_ATTR PIO_DEBOUNCE | PIO_IT_RISE_EDGE
*/

/** SPI MISO pin definition. */
#define SPI_MISO_GPIO 		 (PIO_PA12_IDX)
#define SPI_MISO_FLAGS       (PIO_PERIPH_A | PIO_DEFAULT)
/** SPI MOSI pin definition. */
#define SPI_MOSI_GPIO 		 (PIO_PA13_IDX)
#define SPI_MOSI_FLAGS       (PIO_PERIPH_A | PIO_DEFAULT)
/** SPI SPCK pin definition. */
#define SPI_SPCK_GPIO 		 (PIO_PA14_IDX)
#define SPI_SPCK_FLAGS       (PIO_PERIPH_A | PIO_DEFAULT)

/** SPI chip select 0 pin definition. (Only one configuration is possible) */
#define SPI_NPCS0_GPIO            (PIO_PA11_IDX)
#define SPI_NPCS0_FLAGS           (PIO_TYPE_PIO_OUTPUT_1 | PIO_DEFAULT)


/** TWI0 pins definition */
#define TWI0_DATA_GPIO   PIO_PA3_IDX
#define TWI0_DATA_FLAGS  (PIO_PERIPH_A | PIO_DEFAULT)
#define TWI0_CLK_GPIO    PIO_PA4_IDX
#define TWI0_CLK_FLAGS   (PIO_PERIPH_A | PIO_DEFAULT)


#define PIN_3V3SW            (PIO_PA29_IDX)
#define PIN_3V3SW_FLAGS      (PIO_TYPE_PIO_OUTPUT_1 | PIO_DEFAULT)


#define CONSOLE_UART         UART0
#define CONSOLE_UART_ID      ID_UART0
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

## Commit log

2015-04-06 Initial hardware.
    [Tempest.brd, Tempest.sch]
2015-10-12 -Drone 2 version added.
    [TempestDrone2.brd, TempestDrone2.sch]
2015-10-25 -Migrated to Atmel Studio 7 -Minor improvements/bugfixes
    [ACT_BatteryMonitor.c, ACT_Eye.c, ACT_Solenoid.c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]
2016-01-27 - Minor fixes. - USB added - TAG connect added
    [TempestDrone2.brd, TempestDrone2.sch]
2016-02-03 - Minor improvements
    [TempestDrone2.brd, TempestDrone2.sch]
2016-03-06 - Added 100K between power button and controller - Added part # for fets and diodes
    [Tempest.brd, Tempest.sch]
2016-03-28 - Shocker SFT/NXT Draft
    [TempestShocker.brd, TempestShocker.sch, TempestShockerUpper.brd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]
2016-05-06 - New Shocker upper board for Luxe solenoid - Update of lib
    [TempestDrone2.brd, TempestShockerUpper_V2.brd, TempestShockerUpper_V2.sch]

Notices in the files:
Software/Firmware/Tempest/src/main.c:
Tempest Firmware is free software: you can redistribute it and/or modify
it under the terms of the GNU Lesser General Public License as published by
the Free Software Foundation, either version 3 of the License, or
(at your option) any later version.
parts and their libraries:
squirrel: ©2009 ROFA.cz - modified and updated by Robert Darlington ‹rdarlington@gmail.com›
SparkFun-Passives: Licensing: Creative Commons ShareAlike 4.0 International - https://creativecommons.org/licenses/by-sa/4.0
